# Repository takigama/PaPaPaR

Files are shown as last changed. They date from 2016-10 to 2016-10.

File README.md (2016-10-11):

# PaPaPaR

Short for Paste and Pick and Place and Reflow.

This project is an attempt to create a board that will do solder paste,
pick and place and lastly reflow. Initially I'll be aiming souly at the
pick and place stuff but theres enough componentry on the board to
control the paste and reflow components as well.

It does have enough componentry to also do a single extruder 3d printer
which wasnt exactly a goal, but was a handy alternative function for
the board. 

The board itself is reasonably compact but not a huge amount of work
has gone into it yet.

## Usage

Well, none yet. Haven't even printed the board yet. Currently using
RAMPS as a test bed.

This project is based on the STM32F103 chip and will (at least
initially) use the STM32duino code base with the arduino software
stack for making the thing "go"

You'll need kicad if you want to see the board and once i have a
working model, i'll share it as a project on oshpark!

## Thanks

Thanks go to the folk who do arduino, the folk who do stm32duino, to
the folk who do KiCad and many others probably. As of the current version
the only hardware designer is me... Im also the only coder... and the only
everything else but would welcome others

## Where it starts

The first version will be quite simple. Designed to be controlled with
2 "wiichucks", there is an expectation of having a camera and the pick
and place will be done "manually" but all electrically - i.e. you'll
place componets using joystick with some interesting hot keys and a bit
of camera work.

## It Looks Like This:
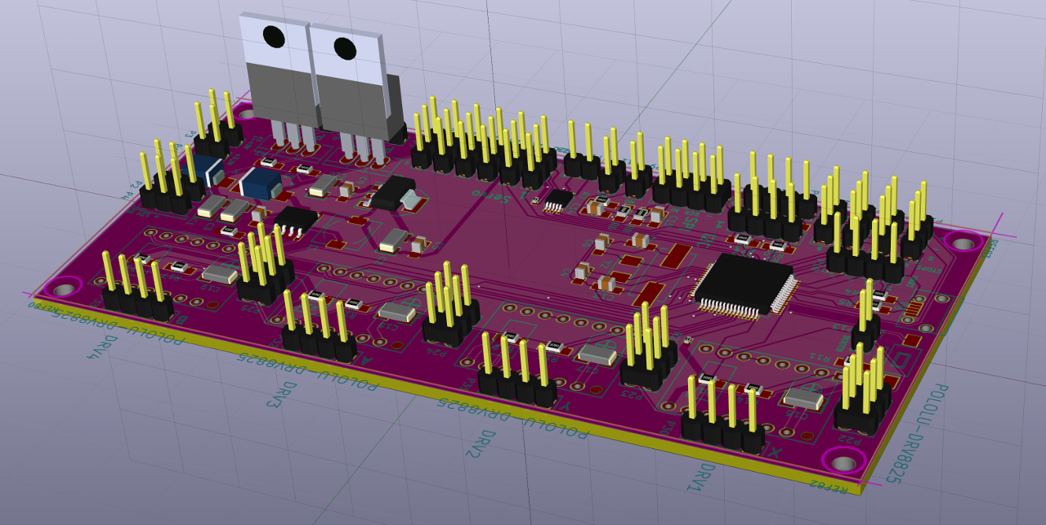
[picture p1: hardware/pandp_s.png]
Top


## What you need

- 3 Steppers (one for the pump)
- Perastaltic pump that can be driving by stepper (or 5-6v DC)
- a pick-up sucktion cup (i have a design for this thats really simple)
- a usb microscope.
- a design for it all to sit on
- a fair amount of imagination and pixie dust!
- a 12v power source

The pump (which is used to hold components) can either be stepper driven
or you can find plenty of 5-6v aquarium pumps on ebay that should surfice
but they want to be less than 1A.

Currently im working on the design of the actual platform for the whole
unit and it will look like a distant cousin of something like the mendel
90 (my fave 3d print) but with a stationary platform and a cartesian type
head. I was VERY tempted to do a delta but am shelving that idea for now

Currently there also exists no code but watch this space - some will
definitely be borrowed from the sprinter/marlin code bases but no code
yet exists.

## Things To Note

1. Its designed to be possible to hand solder (which is how I will build
it)

2. I take no responsibility if it does anything negative!

3. Its alpha

4. Im not the worlds greatest hardware designer (or even a good one)!

5. Currently doesnt have a license - feel free to do as you will, but will
ultimately be licensed under a compatible open source license (GPL for code
as an example)

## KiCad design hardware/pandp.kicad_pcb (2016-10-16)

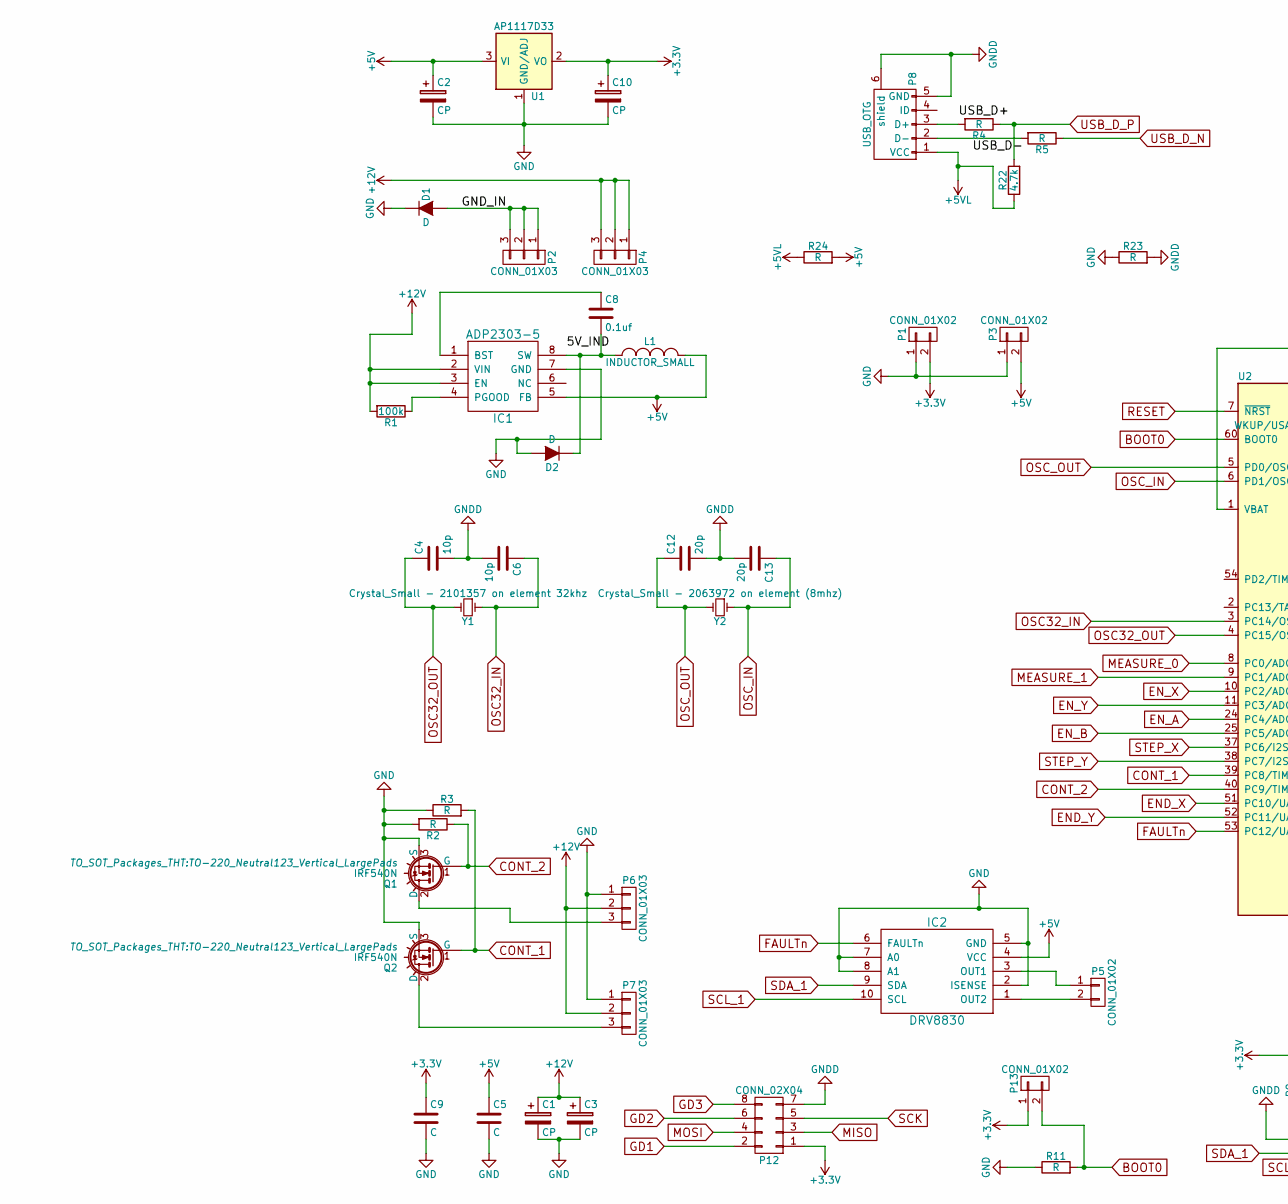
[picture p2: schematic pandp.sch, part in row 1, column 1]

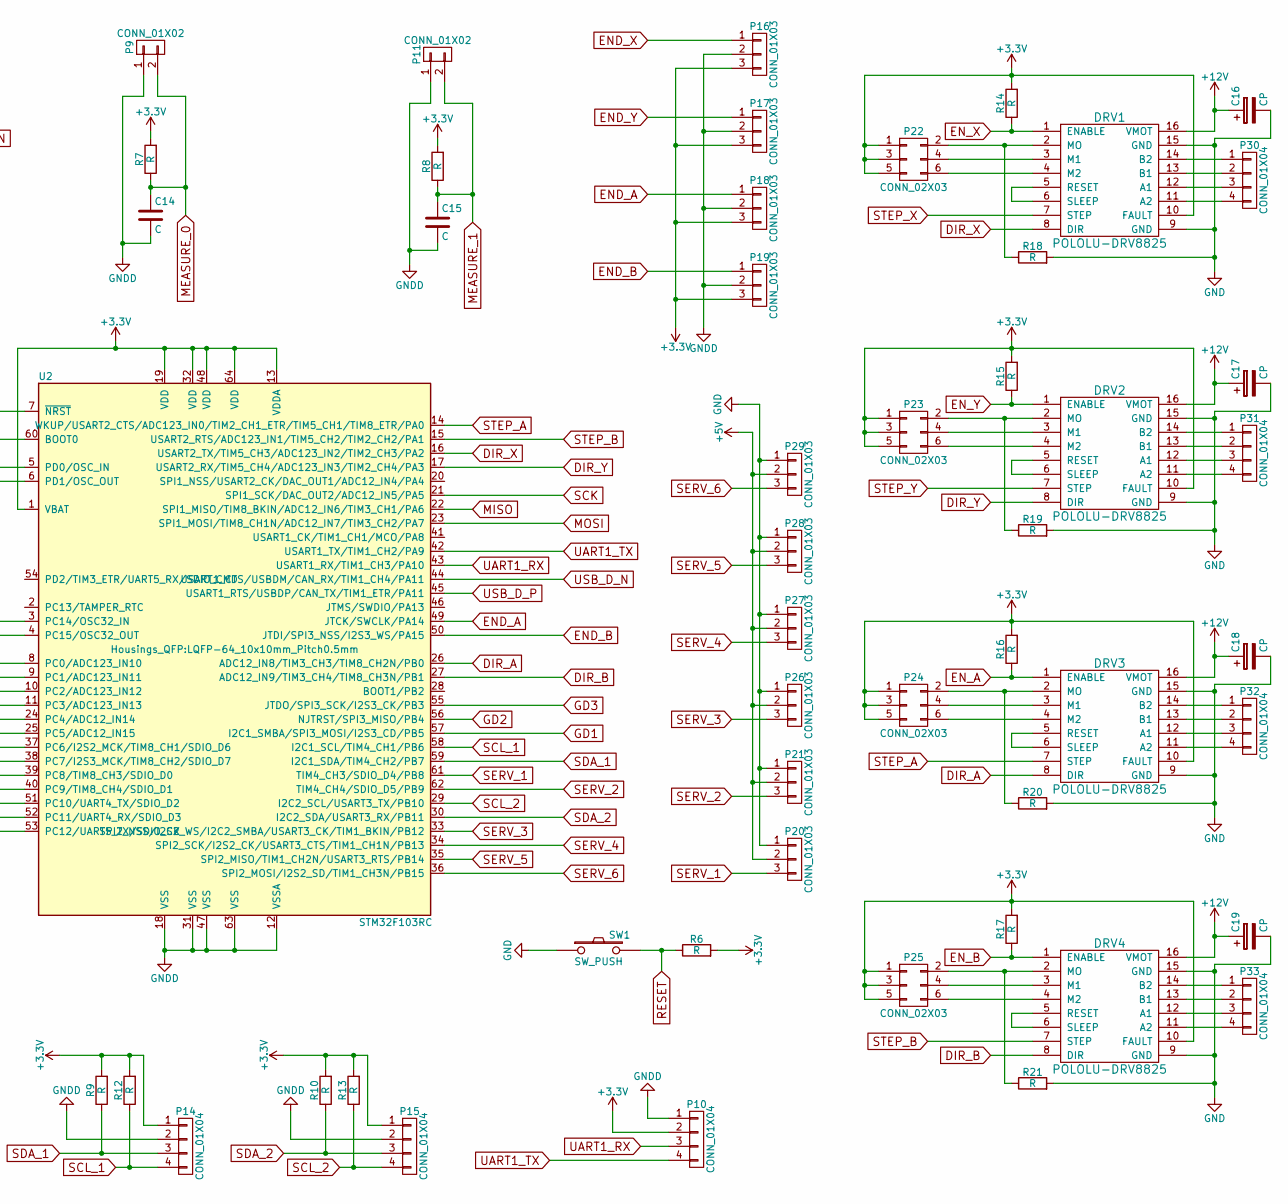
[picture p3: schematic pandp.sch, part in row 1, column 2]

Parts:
C1, C2, C3, C10, C16, C17, C18, C19: CP; SMD-1210_Pol
C4, C6: 10p; C_0805_HandSoldering
C5, C9, C14, C15: C; C_0805_HandSoldering
C8: 0.1uf; C_0805_HandSoldering
C12, C13: 20p; C_0805_HandSoldering
D1, D2: D; SMB_Handsoldering
DRV1, DRV2, DRV3, DRV4: POLOLU-DRV8825
IC1: ADP2303-5; SOIC-8_3.9x4.9mm_Pitch1.27mm
IC2: DRV8830; TSSOP-10_3x3mm_Pitch0.5mm
L1: INDUCTOR_SMALL; Choke_SMD_7.3x7.3_H3.5
P1, P3, P5, P9, P11, P13: CONN_01X02; Pin_Header_Straight_1x02
P2, P4, P6, P7, P16, P17, P18, P19, P20, P21, P26, P27, P28, P29: CONN_01X03; Pin_Header_Straight_1x03
P8: USB_OTG; USB_Micro-B-OshPark
P10, P14, P15, P30, P31, P32, P33: CONN_01X04; Pin_Header_Straight_1x04
P12: CONN_02X04; Pin_Header_Straight_2x04
P22, P23, P24, P25: CONN_02X03; Pin_Header_Straight_2x03
Q1, Q2: IRF540N; TO-220_Neutral123_Vertical_LargePads
R1: 100k; R_0805_HandSoldering
R2, R3, R4, R5, R6, R7, R8, R9, R10, R11, R12, R13, R14, R15, R16, R17, R18, R19, R20, R21: R; R_0805_HandSoldering
R22: 4.7k; R_0805_HandSoldering
R23, R24: R; R_0402
SW1: SW_PUSH; SW_SPST_FSMSM
U1: AP1117D33; SOT-223
U2: STM32F103RC; LQFP-64_10x10mm_Pitch0.5mm
Y1: Crystal_Small - 2101357 on element 32khz; ABM3
Y2: Crystal_Small - 2063972 on element (8mhz); Crystal_HC49-SD_SMD

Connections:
+3V3: C9.1, C10.1, DRV1.10 (FAULT), DRV2.10 (FAULT), DRV3.10 (FAULT), DRV4.10 (FAULT), P1.2, P10.2, P12.1, P13.1, P14.1, P15.1, P16.3, P17.3, P18.3, P19.3, P22.1, P22.3, P22.5, P23.1, P23.3, P23.5, P24.1, P24.3, P24.5, P25.1, P25.3, P25.5, R6.2, R7.2, R8.2, R9.2, R10.2, R12.2, R13.2, R14.2, R15.2, R16.2, R17.2, U1.2 (VO), U2.1 (VBAT), U2.13 (VDDA), U2.19 (VDD), U2.32 (VDD), U2.48 (VDD), U2.64 (VDD)
+5V: C2.1, C5.1, IC1.5 (FB), IC2.4 (VCC), L1.2, P3.2, P20.2, P21.2, P26.2, P27.2, P28.2, P29.2, R24.2, U1.3 (VI)
+5VL: P8.1 (VCC), R22.1, R24.1
+12V: C1.1, C3.1, C16.1, C17.1, C18.1, C19.1, DRV1.16 (VMOT), DRV2.16 (VMOT), DRV3.16 (VMOT), DRV4.16 (VMOT), IC1.2 (VIN), IC1.3 (EN), P4.1, P4.2, P4.3, P6.2, P7.2, R1.2
/GND_IN: D1.2 (A), P2.1, P2.2, P2.3
BOOT0: P13.2, R11.2, U2.60 (BOOT0)
CONT_1: Q2.1 (G), R3.2, U2.39 (PC8/TIM8_CH3/SDIO_D0)
CONT_2: Q1.1 (G), R2.1, U2.40 (PC9/TIM8_CH4/SDIO_D1)
DIR_A: DRV3.8 (DIR), U2.26 (ADC12_IN8/TIM3_CH3/TIM8_CH2N/PB0)
DIR_B: DRV4.8 (DIR), U2.27 (ADC12_IN9/TIM3_CH4/TIM8_CH3N/PB1)
DIR_X: DRV1.8 (DIR), U2.16 (USART2_TX/TIM5_CH3/ADC123_IN2/TIM2_CH3/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)
DIR_Y: DRV2.8 (DIR), U2.17 (USART2_RX/TIM5_CH4/ADC123_IN3/TIM2_CH4/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)
END_A: P18.1, U2.49 (JTCK/SWCLK/PA14)
END_B: P19.1, U2.50 (JTDI/SPI3_NSS/I2S3_WS/PA15)
END_X: P16.1, U2.51 (PC10/UART4_TX/SDIO_D2)
END_Y: P17.1, U2.52 (PC11/UART4_RX/SDIO_D3)
EN_A: DRV3.1 (ENABLE), R16.1, U2.24 (PC4/ADC12_IN14)
EN_B: DRV4.1 (ENABLE), R17.1, U2.25 (PC5/ADC12_IN15)
EN_X: DRV1.1 (ENABLE), R14.1, U2.10 (PC2/ADC123_IN12)
EN_Y: DRV2.1 (ENABLE), R15.1, U2.11 (PC3/ADC123_IN13)
FAULTn: IC2.6 (FAULTn), U2.53 (PC12/UART5_TX/SDIO_CK)
GD1: P12.2, U2.57 (I2C1_SMBA/SPI3_MOSI/I2S3_CD/PB5)
GD2: P12.6, U2.56 (NJTRST/SPI3_MISO/PB4)
GD3: P12.8, U2.55 (JTDO/SPI3_SCK/I2S3_CK/PB3)
GND: C1.2, C2.2, C3.2, C5.2, C9.2, C10.2, C16.2, C17.2, C18.2, C19.2, D1.1 (K), D2.2 (A), DRV1.9 (GND), DRV1.15 (GND), DRV2.9 (GND), DRV2.15 (GND), DRV3.9 (GND), DRV3.15 (GND), DRV4.9 (GND), DRV4.15 (GND), IC1.7 (GND), IC2.2 (ISENSE), IC2.5 (GND), IC2.7 (A0), IC2.8 (A1), P1.1, P3.1, P6.1, P7.1, P20.1, P21.1, P26.1, P27.1, P28.1, P29.1, Q1.3 (S), Q2.3 (S), R2.2, R3.1, R11.1, R18.2, R19.2, R20.2, R21.2, R23.1, SW1.1, U1.1 (GND/ADJ)
GNDD: C4.2, C6.2, C12.2, C13.2, C14.2, C15.2, P8.5 (GND), P8.6 (shield), P9.1, P10.1, P11.1, P12.7, P14.2, P15.2, P16.2, P17.2, P18.2, P19.2, R23.2, U2.12 (VSSA), U2.18 (VSS), U2.31 (VSS), U2.47 (VSS), U2.63 (VSS)
MEASURE_0: C14.1, P9.2, R7.1, U2.8 (PC0/ADC123_IN10)
MEASURE_1: C15.1, P11.2, R8.1, U2.9 (PC1/ADC123_IN11)
MISO: P12.3, U2.22 (SPI1_MISO/TIM8_BKIN/ADC12_IN6/TIM3_CH1/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)
MOSI: P12.4, U2.23 (SPI1_MOSI/TIM8_CH1N/ADC12_IN7/TIM3_CH2/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)
unnamed: C8.1, IC1.1 (BST)
unnamed: C8.2, D2.1 (K), IC1.8 (SW), L1.1
unnamed: DRV1.2 (MO), P22.2, R18.1
unnamed: DRV1.3 (M1), P22.4
unnamed: DRV1.4 (M2), P22.6
unnamed: DRV1.5 (RESET), DRV1.6 (SLEEP)
unnamed: DRV1.11 (A2), P30.4
unnamed: DRV1.12 (A1), P30.3
unnamed: DRV1.13 (B1), P30.2
unnamed: DRV1.14 (B2), P30.1
unnamed: DRV2.2 (MO), P23.2, R19.1
unnamed: DRV2.3 (M1), P23.4
unnamed: DRV2.4 (M2), P23.6
unnamed: DRV2.5 (RESET), DRV2.6 (SLEEP)
unnamed: DRV2.11 (A2), P31.4
unnamed: DRV2.12 (A1), P31.3
unnamed: DRV2.13 (B1), P31.2
unnamed: DRV2.14 (B2), P31.1
unnamed: DRV3.2 (MO), P24.2, R20.1
unnamed: DRV3.3 (M1), P24.4
unnamed: DRV3.4 (M2), P24.6
unnamed: DRV3.5 (RESET), DRV3.6 (SLEEP)
unnamed: DRV3.11 (A2), P32.4
unnamed: DRV3.12 (A1), P32.3
unnamed: DRV3.13 (B1), P32.2
unnamed: DRV3.14 (B2), P32.1
unnamed: DRV4.2 (MO), P25.2, R21.1
unnamed: DRV4.3 (M1), P25.4
unnamed: DRV4.4 (M2), P25.6
unnamed: DRV4.5 (RESET), DRV4.6 (SLEEP)
unnamed: DRV4.11 (A2), P33.4
unnamed: DRV4.12 (A1), P33.3
unnamed: DRV4.13 (B1), P33.2
unnamed: DRV4.14 (B2), P33.1
unnamed: IC1.4 (PGOOD), R1.1
unnamed: IC2.1 (OUT2), P5.2
unnamed: IC2.3 (OUT1), P5.1
unnamed: P6.3, Q1.2 (D)
unnamed: P7.3, Q2.2 (D)
unnamed: P8.2 (D-), R5.2
unnamed: P8.3 (D+), R4.2
OSC32_IN: C6.1, U2.3 (PC14/OSC32_IN), Y1.1
OSC32_OUT: C4.1, U2.4 (PC15/OSC32_OUT), Y1.2
OSC_IN: C13.1, U2.6 (PD1/OSC_OUT), Y2.1
OSC_OUT: C12.1, U2.5 (PD0/OSC_IN), Y2.2
RESET: R6.1, SW1.2, U2.7 (~NRST)
SCK: P12.5, U2.21 (SPI1_SCK/DAC_OUT2/ADC12_IN5/PA5)
SCL_1: IC2.10 (SCL), P14.4, R12.1, U2.58 (I2C1_SCL/TIM4_CH1/PB6)
SCL_2: P15.4, R13.1, U2.29 (I2C2_SCL/USART3_TX/PB10)
SDA_1: IC2.9 (SDA), P14.3, R9.1, U2.59 (I2C1_SDA/TIM4_CH2/PB7)
SDA_2: P15.3, R10.1, U2.30 (I2C2_SDA/USART3_RX/PB11)
SERV_1: P20.3, U2.61 (TIM4_CH3/SDIO_D4/PB8)
SERV_2: P21.3, U2.62 (TIM4_CH4/SDIO_D5/PB9)
SERV_3: P26.3, U2.33 (SPI2_NSS/I2S2_WS/I2C2_SMBA/USART3_CK/TI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)
SERV_4: P27.3, U2.34 (SPI2_SCK/I2S2_CK/USART3_CTS/TIM1_CH1N/P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)
SERV_5: P28.3, U2.35 (SPI2_MISO/TIM1_CH2N/USART3_RTS/PB14)
SERV_6: P29.3, U2.36 (SPI2_MOSI/I2S2_SD/TIM1_CH3N/PB15)
STEP_A: DRV3.7 (STEP), U2.14 (WKUP/USART2_CTS/ADC123_IN0/TIM2_CH1_ETR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)
STEP_B: DRV4.7 (STEP), U2.15 (USART2_RTS/ADC123_IN1/TIM5_CH2/TIM2_CH2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)
STEP_X: DRV1.7 (STEP), U2.37 (PC6/I2S2_MCK/TIM8_CH1/SDIO_D6)
STEP_Y: DRV2.7 (STEP), U2.38 (PC7/I2S3_MCK/TIM8_CH2/SDIO_D7)
UART1_RX: P10.3, U2.43 (USART1_RX/TIM1_CH3/PA10)
UART1_TX: P10.4, U2.42 (USART1_TX/TIM1_CH2/PA9)
USB_D_N: R5.1, U2.44 (USART1_CTS/USBDM/CAN_RX/TIM1_CH4/PA11)
USB_D_P: R4.1, R22.2, U2.45 (USART1_RTS/USBDP/CAN_TX/TIM1_ETR/PA11)

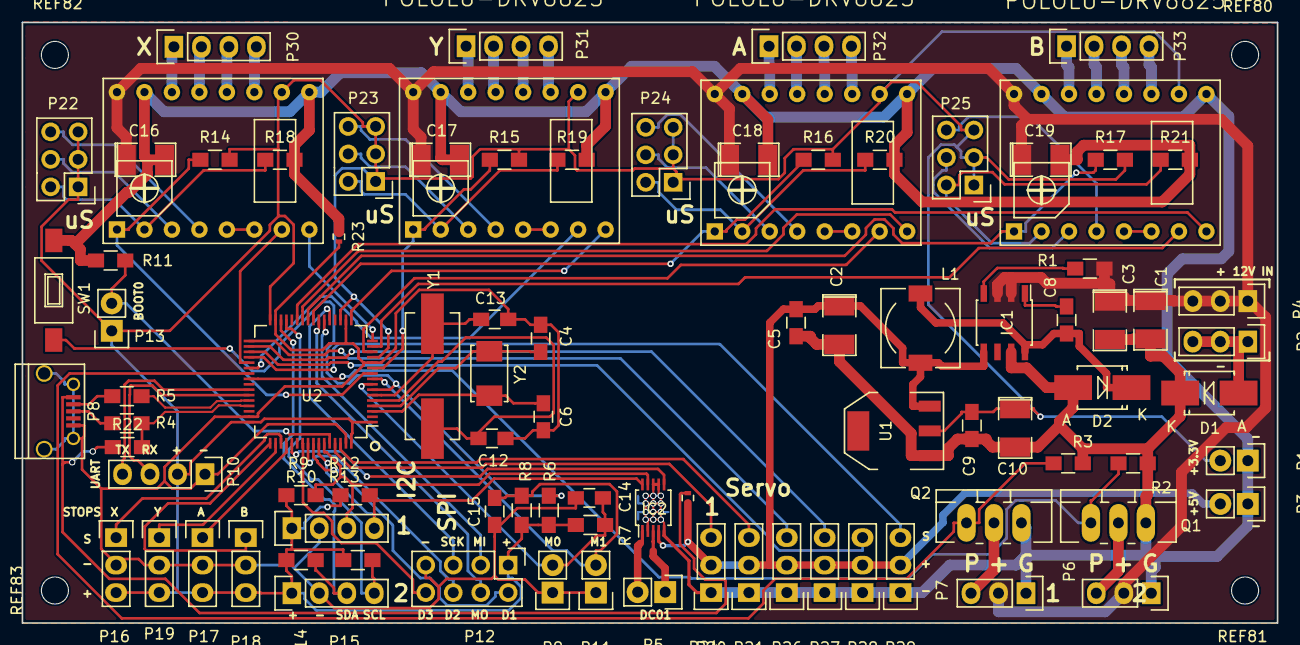
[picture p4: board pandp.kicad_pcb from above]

Board: 2 copper layers, 116.0 x 55.5 mm, 94 parts (0 on the bottom side), 95 nets.

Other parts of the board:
REF80, REF81, REF82, REF83: MountingHole_2-5mm

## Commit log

2016-10-05 Initial PaPPaR import
    [pandp.dsn, pandp.kicad_pcb, pandp.sch]
2016-10-06 first autorouter - dont like
    [pandp.dsn, pandp.kicad_pcb, pandp.sch]
2016-10-06 power self-routed
    [pandp.dsn, pandp.kicad_pcb]
2016-10-07 final - V1
    [pandp.kicad_pcb]
2016-10-07 Moving to new layout
    [pandp.dsn, pandp.kicad_pcb, pandp.sch]
2016-10-07 rename dir
    [pandp.dsn, pandp.kicad_pcb, pandp.sch]
2016-10-07 minor change to board text
    [pandp.kicad_pcb]
2016-10-11 added 5v dc motor control - low current - 500ma or less
    [pandp.dsn, pandp.kicad_pcb, pandp.sch]
2016-10-11 Readme update
    [pandp.kicad_pcb]
2016-10-12 oshpark compatible holes for uusb connector
    [pandp.kicad_pcb]
2016-10-12 new uusb oshpark compatible, added a mark for the stm chip pin 0
    [pandp.kicad_pcb, pandp.sch]
2016-10-15 added pullup for usb
    [pandp.kicad_pcb, pandp.sch]
2016-10-16 removed the terrible frame from hell
    [pandp.kicad_pcb, pandp.sch]
2016-10-16 changed a few small routes, added vias for cooling on dc conroller
    [pandp.kicad_pcb]
